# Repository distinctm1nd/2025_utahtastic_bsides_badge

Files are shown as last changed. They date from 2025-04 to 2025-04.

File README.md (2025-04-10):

# 2025 Utahtastic BSides Badge

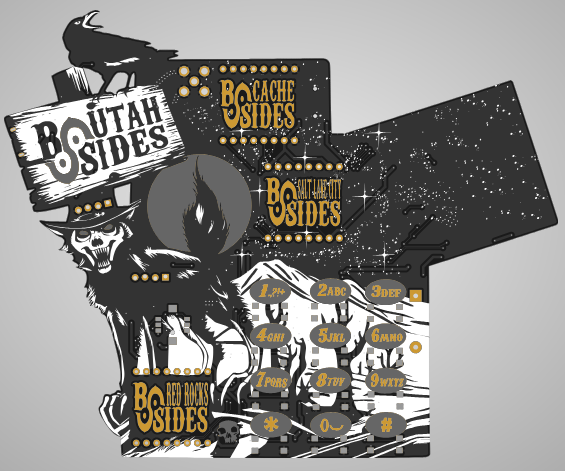
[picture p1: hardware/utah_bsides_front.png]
Utah BSides Badge front


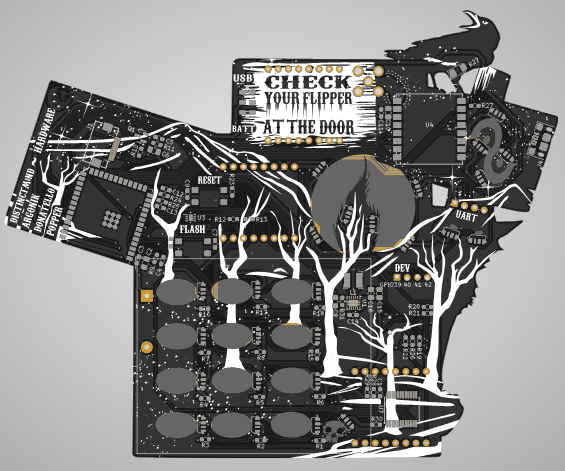
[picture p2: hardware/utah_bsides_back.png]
Utah BSides Badge front


Key Features:

    - ESP32-S3-WROOM Microcontroller
    - LoRa 
    - 25 Addressable LEDs
    - TFT Display
    - Power Options: Powered via Micro USB or 3 AA batteries (regulated at 3.3V).
    - Hackable and Programmable: Easily program with just a laptop and a Micro USB cable.
    - Expansion Ready: 3 minibadge slots for future add-ons.
    - Custom Meshtastic Firmware: Open-source firmware designed for mesh networking.
    - Convenient Controls – UART connection point, Reset and Flash buttons, and a power switch for toggling between USB and battery modes.
    - 4 GPIO pins available for custom dev work

## Make sure you have the following items:

- Badge
- 6 Minibadge headers
- Battery holder
- Moon LED diffuser
- 3 AA Batteries
- Lanyard
- Minibadge kit
- Double sided foam tape

## Badge Assembly

The badge does not require further assembly to be functional by powering through the USB with an external battery. Make sure that the switch is at USB if powering with USB. 

To complete the assembly, first solder the minibadge headers to the badge. Be careful while soldering the header that is near the display. 

After this, solder the battery holder and apply foam tape to hold the end without solder connectors in place. 

Use hot glue to attach the moon diffuser to moon on the back of the badge. 

Attach the lanyard to the "post" by the raven. 

## Minibadge Assembly

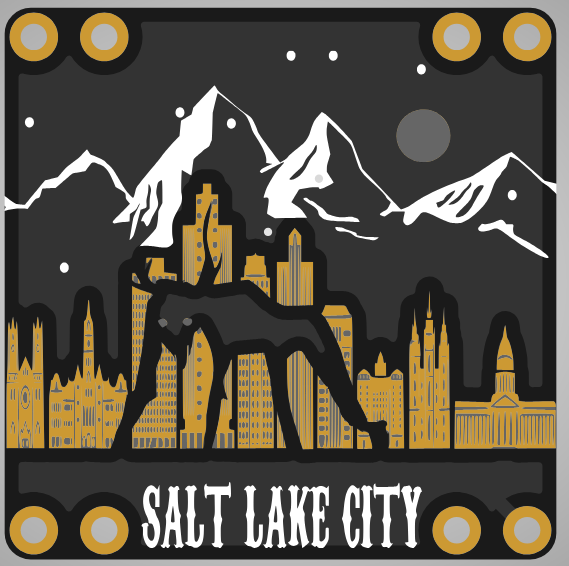
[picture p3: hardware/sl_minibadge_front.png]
Utah BSides Badge front


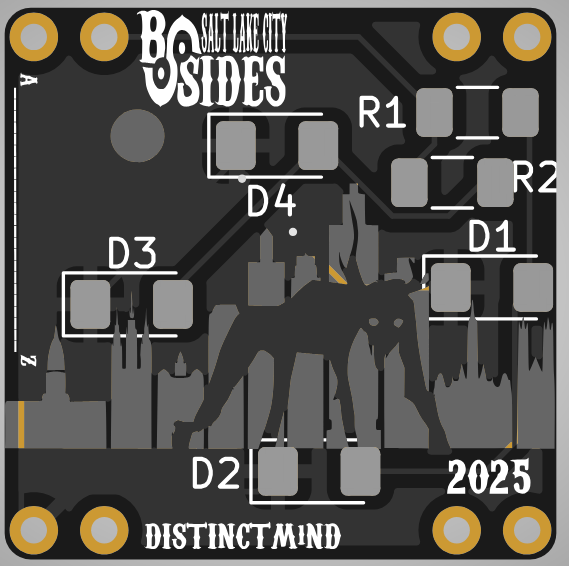
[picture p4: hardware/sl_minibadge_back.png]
Utah BSides Badge front


- Solder the 68 ohm (1206) resistors to R1 and R2. These can be oriented any direction. 
- Solder the LEDs (yellow) to D1, D2, D3 and D4. Orientation on these matters. The green mark is on the cathode side of the LED so it needs to be oriented toward the cathode side on the PCB. The cathode side on the PCB is marked by a box around it. 

- Solder the headers to the four corners. 

## Keyboard Functionality

5-Way Switch
- Up: send message
- Down: erase/backspace
- Left: move cursor left
- Right: move cursor right
- Press: switch screens

## STL Files for joystick button cap and moon diffuser

[Joystick Button Cap](https://www.printables.com/model/1166931-joystick-cap-for-b-sides-utah-2025-badge)

[Moon Diffuser](https://www.printables.com/model/1166783-moon-led-diffuser-for-b-sides-utah-2025-badge)

## A few notes on usage

Don't transmit without the antenna attached as you could damage the badge. 

If you download the meshtastic app you can connect to your badge via bluetooth and send /receive messages through the app. You can also change many setting through the app. 

Make sure that you are on the Medium Fast channel for the conference. 

To change the moon LED color or brightness, in the app, go to:
- Radio Configuration -> Ambient Lighting

Once in the ambient lighting config you can change the brightness of the moon LEDs by changing "Current" to a different number. 255 is max brightness and anything less than that is dimmer. You can change the color codes for Red, Green and Blue to generate different colors. 

If you can't send or receive messages make sure that the LoRa channel is not on long fast. For the conference we'll be using medium fast. 

If the badge doesn't start up when turned on then push the reset button.

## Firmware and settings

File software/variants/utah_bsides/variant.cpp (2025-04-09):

#include "../main.h"
#include "../configuration.h"
#include <Wire.h>
#include "variant.h"
#include <Adafruit_NeoPixel.h>
#include <Preferences.h>
#include "NodeDB.h"

// I2C Expander (TCA9535)
#define TCA9535_ADDRESS 0x20
#define BUTTON_SDA 1
#define BUTTON_SCL 2
#define BUTTON_INT 15

extern graphics::Screen *screen;


// are we showing the welcome screen
int welcomeScreenActivated = 0;

/*-----------------------------------------------------------------------
Definitions and variables for LEDs
-----------------------------------------------------------------------*/
void handleButtonLedFlashing();
void handleChasingLedPatterns();
void handleColorArrayChange();

// Variables for fading button LEDs
unsigned long lastButtonFadeTime = 0;
const unsigned long fadeInterval = 150;  

// Variables for rainbow colors and fading logic
int currentColorIndex = 0;  
float fadeProgress[BUTTON_LED_COUNT] = {0};  
float fadeProgressEye[LOGO_EYE_LED_COUNT] = {0}; 
const float transitionSpeed = 0.01;  

// Variables for chasing eye LEDs
unsigned long lastChaseTime = 0;
const unsigned long chaseInterval = 150; 
int currentLedIndex = 0;  

// Initialize LED objects directly
Adafruit_NeoPixel button_leds(BUTTON_LED_COUNT, BUTTON_LED_PIN, NEO_GRB + NEO_KHZ800);
Adafruit_NeoPixel logo_eye_leds(LOGO_EYE_LED_COUNT, LOGO_EYE_LED_PIN, NEO_GRB + NEO_KHZ800);

const int COLORSCOUNT = 7;

const uint32_t rainbowColors[COLORSCOUNT] = {
    0xFF0000,    // Red
    0xFF00FF,    // Magenta
    0xFFD700,    // Yellow
    0x006400,    // Green
    0x00FF00,    // Blue
    0x800080,    // Indigo
    0xFF1493     // Violet
};

const uint32_t blueWhiteColors[COLORSCOUNT] = {
    0x0000FF,    // Blue
    0xFFFFFF,    // White
    0x0000FF,    // Blue
    0xFFFFFF,    // White
    0x0000FF,    // Blue
    0xFFFFFF,    // White
    0x0000FF     // Blue
};

const uint32_t redMaroonColors[COLORSCOUNT] = {
    0xFF0000,    // Red
    0x800000,    // Maroon
    0xFF0000,    // Red
    0x800000,    // Maroon
    0xFF0000,    // Red
    0x800000,    // Maroon
    0xFF0000     // Red
};

const uint32_t pinkWhiteColors[COLORSCOUNT] = {
    0xFF00FF,    // Pink
    0xFFFFFF,    // White
    0xFF00FF,    // Pink
    0xFFFFFF,    // White
    0xFF00FF,    // Pinkc
    0xFFFFFF,    // White
    0xFF00FF     // Pink
};

const uint32_t pinkPurpleColors[COLORSCOUNT] = {
    0xFF00FF,    // Pink
    0x4B0082,    // Purple
    0xFF00FF,    // Pink
    0x4B0082,    // Purple
    0xFF00FF,    // Pink
    0x4B0082,    // Purple
    0xFF00FF     // Pink
};

const uint32_t greenBlueColors[COLORSCOUNT] = {
    0x00FF00,    // Green
    0x0000FF,    // Blue
    0x00FF00,    // Green
    0x0000FF,    // Blue
    0x00FF00,    // Green
    0x0000FF,    // Blue
    0x00FF00     // Green
};

const uint32_t ledsOff[COLORSCOUNT] = {
    0x000000,    // Black
    0x000000,    // Black
    0x000000,    // Black
    0x000000,    // Black
    0x000000,    // Black
    0x000000,    // Black
    0x000000     // Black
};

const int COLORARRAYCOUNT = 7;
const uint32_t* colorArrays[COLORARRAYCOUNT] = {rainbowColors, blueWhiteColors, redMaroonColors, pinkWhiteColors, pinkPurpleColors, greenBlueColors, ledsOff};

uint32_t activeColorArrayIndex = 0;

/*-----------------------------------------------------------------------
TCA9535 FUNCTIONS --- Keyboard
-----------------------------------------------------------------------*/

#define USE_KEYBOARD_INTERRUPT false

#define KEY(x) meshtastic_ModuleConfig_CannedMessageConfig_InputEventChar_##x

enum ButtonBit {
    BUTTON_BOTLEFT  = 1<<0,
    BUTTON_ZERO     = 1<<1,
    BUTTON_BOTRIGHT = 1<<2,
    BUTTON_NINE     = 1<<3,
    BUTTON_EIGHT    = 1<<4,
    BUTTON_SEVEN    = 1<<5,
    BUTTON_SIX      = 1<<6,
    BUTTON_FIVE     = 1<<7,
    BUTTON_FOUR     = 1<<8,
    BUTTON_THREE    = 1<<9,
    BUTTON_TWO      = 1<<10,
    BUTTON_ONE      = 1<<11,
    BUTTON_UP       = 1<<12,
    BUTTON_RIGHT    = 1<<13,
    BUTTON_DOWN     = 1<<14,
    BUTTON_LEFT     = 1<<15
};

char keys[][6] = {
    {'*',   0,   0,   0,   0,   0},
    {' ', '0',   0,   0,   0,   0},
    {'#',   0,   0,   0,   0,   0},
    {'w', 'x', 'y', 'z', '9',   0},
    {'t', 'u', 'v', '8',   0,   0},
    {'p', 'q', 'r', 's', '7',   0},
    {'m', 'n', 'o', '6',   0,   0},
    {'j', 'k', 'l', '5',   0,   0},
    {'g', 'h', 'i', '4',   0,   0},
    {'d', 'e', 'f', '3',   0,   0},
    {'a', 'b', 'c', '2',   0,   0},
    {'.', ',', '?', '!', '+', '1'},
    {KEY(UP),    0, 0, 0, 0, 0},
    {KEY(RIGHT), 0, 0, 0, 0, 0},
    {KEY(DOWN),  0, 0, 0, 0, 0},
    {KEY(LEFT),  0, 0, 0, 0, 0}
};

#define NUM_ELEMS(a) (sizeof(a)/sizeof a[0])
int konami_code[] = {BUTTON_UP, BUTTON_UP, BUTTON_DOWN, BUTTON_DOWN, BUTTON_LEFT, BUTTON_RIGHT, BUTTON_LEFT, BUTTON_RIGHT, BUTTON_TWO, BUTTON_TWO};
#define KONAMI_CODE_LEN NUM_ELEMS(konami_code)

// forward declaration for use in the keyboard class
void drawMenuScreen(OLEDDisplay *display, OLEDDisplayUiState *state, int16_t x, int16_t y);

void initializeTCA9535() {
    Wire.beginTransmission(TCA9535_ADDRESS);
    Wire.write(0x06); // Set all pins as inputs
    Wire.endTransmission();
}

uint16_t readButtonState() {
    Wire.beginTransmission(TCA9535_ADDRESS);
    Wire.write(0x00); // Request input port 0
    Wire.endTransmission();
    Wire.requestFrom(TCA9535_ADDRESS, 2);
    uint16_t state = Wire.read() | (Wire.read() << 8);
    return ~state;
}

void intPressHandler();
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

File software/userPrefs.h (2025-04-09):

#ifndef _USERPREFS_
#define _USERPREFS_

// Slipstream values:

#define USERPREFS_TZ_STRING "tzplaceholder                                         "

// Uncomment and modify to set device defaults

// #define USERPREFS_EVENT_MODE 1

#define USERPREFS_CONFIG_LORA_REGION meshtastic_Config_LoRaConfig_RegionCode_US
#define USERPREFS_LORACONFIG_MODEM_PRESET meshtastic_Config_LoRaConfig_ModemPreset_MEDIUM_FAST
// #define USERPREFS_LORACONFIG_CHANNEL_NUM 31
// #define USERPREFS_CONFIG_LORA_IGNORE_MQTT true

// #define USERPREFS_CONFIG_GPS_MODE meshtastic_Config_PositionConfig_GpsMode_ENABLED

// #define USERPREFS_CHANNELS_TO_WRITE 3
/*
#define USERPREFS_CHANNEL_0_PSK \
    {                                                                                                                            \
        0x38, 0x4b, 0xbc, 0xc0, 0x1d, 0xc0, 0x22, 0xd1, 0x81, 0xbf, 0x36, 0xb8, 0x61, 0x21, 0xe1, 0xfb, 0x96, 0xb7, 0x2e, 0x55,  \
            0xbf, 0x74, 0x22, 0x7e, 0x9d, 0x6a, 0xfb, 0x48, 0xd6, 0x4c, 0xb1, 0xa1                                               \
    }
*/
// #define USERPREFS_CHANNEL_0_NAME "DEFCONnect"
// #define USERPREFS_CHANNEL_0_PRECISION 14
// #define USERPREFS_CHANNEL_0_UPLINK_ENABLED true
// #define USERPREFS_CHANNEL_0_DOWNLINK_ENABLED true
/*
#define USERPREFS_CHANNEL_1_PSK \
    {                                                                                                                            \
        0x00, 0x00, 0x00, 0x00, 0x00, 0x00, 0x00, 0x00, 0x00, 0x00, 0x00, 0x00, 0x00, 0x00, 0x00, 0x00, 0x00, 0x00, 0x00, 0x00,  \
            0x00, 0x00, 0x00, 0x00, 0x00, 0x00, 0x00, 0x00, 0x00, 0x00, 0x00, 0x00                                               \
    }
*/
// #define USERPREFS_CHANNEL_1_NAME "REPLACEME"
// #define USERPREFS_CHANNEL_1_PRECISION 14
// #define USERPREFS_CHANNEL_1_UPLINK_ENABLED true
// #define USERPREFS_CHANNEL_1_DOWNLINK_ENABLED true
/*
#define USERPREFS_CHANNEL_2_PSK \
    {                                                                                                                            \
        0x00, 0x00, 0x00, 0x00, 0x00, 0x00, 0x00, 0x00, 0x00, 0x00, 0x00, 0x00, 0x00, 0x00, 0x00, 0x00, 0x00, 0x00, 0x00, 0x00,  \
            0x00, 0x00, 0x00, 0x00, 0x00, 0x00, 0x00, 0x00, 0x00, 0x00, 0x00, 0x00                                              \
    }
*/
// #define USERPREFS_CHANNEL_2_NAME "REPLACEME"
// #define USERPREFS_CHANNEL_2_PRECISION 14
// #define USERPREFS_CHANNEL_2_UPLINK_ENABLED true
// #define USERPREFS_CHANNEL_2_DOWNLINK_ENABLED true

// #define USERPREFS_CONFIG_OWNER_LONG_NAME "My Long Name"
// #define USERPREFS_CONFIG_OWNER_SHORT_NAME "MLN"


#define USERPREFS_SPLASH_TITLE "UTAHtastic"
#define icon_width 100
#define icon_height 87
#define USERPREFS_HAS_SPLASH

static unsigned char icon_bits[] = {
 0x00, 0x00, 0x00, 0x40, 0x7f, 0x00, 0x00, 0x00, 0x00, 0x00, 0x00, 0x00, 0x00, 0x00, 0x00, 0x2a, 
	0xe8, 0xa3, 0x00, 0x00, 0x00, 0x00, 0x00, 0x00, 0x00, 0x00, 0x00, 0xc0, 0xff, 0x47, 0x50, 0x01, 
	0x00, 0x00, 0x00, 0x00, 0x00, 0x00, 0x00, 0x00, 0xf8, 0xff, 0x07, 0x7c, 0x00, 0x00, 0x00, 0x00, 
	0x00, 0x00, 0x00, 0x00, 0x00, 0xfc, 0xff, 0x07, 0x1f, 0x00, 0x00, 0x00, 0x00, 0x00, 0x00, 0x00, 
	0x00, 0x00, 0xfe, 0xe8, 0x83, 0x07, 0x00, 0x00, 0x00, 0x00, 0x00, 0x00, 0x00, 0x00, 0x00, 0xff, 
	0xc1, 0xf1, 0x01, 0x00, 0x00, 0x00, 0x00, 0x00, 0x00, 0x00, 0x00, 0x80, 0xff, 0xff, 0xf8, 0x00, 
	0x00, 0x00, 0x00, 0x00, 0x00, 0x00, 0x00, 0x00, 0xc0, 0xff, 0x7f, 0x7c, 0x00, 0x00, 0x00, 0x00, 
	0x00, 0x00, 0x00, 0x00, 0x00, 0xe0, 0xff, 0x3f, 0x3e, 0x00, 0x00, 0x00, 0x00, 0x00, 0x00, 0x00, 
	0x00, 0x00, 0xf0, 0xff, 0x7f, 0x1c, 0x00, 0x00, 0x00, 0x00, 0x00, 0x00, 0x00, 0x00, 0x00, 0xf8, 
	0xff, 0x7f, 0x38, 0x00, 0x00, 0x00, 0x00, 0x00, 0x00, 0x00, 0x00, 0x00, 0xfc, 0xff, 0xff, 0x71, 
	0x00, 0x00, 0x00, 0x00, 0x00, 0x00, 0x00, 0x00, 0x00, 0xfe, 0xff, 0xff, 0x83, 0x03, 0x00, 0x00, 
	0x00, 0x00, 0x00, 0x00, 0x00, 0x00, 0xff, 0xff, 0xff, 0x5f, 0x15, 0x00, 0x00, 0x00, 0x00, 0x00, 
	0x00, 0x00, 0x00, 0xfe, 0xff, 0xff, 0xff, 0x3b, 0x00, 0x00, 0x00, 0x00, 0x00, 0x00, 0x00, 0x00, 
	0xff, 0xff, 0xff, 0xff, 0x77, 0x00, 0x00, 0x00, 0x00, 0x00, 0x00, 0x00, 0x00, 0xff, 0xff, 0xff, 
	0x7f, 0xf2, 0x00, 0x00, 0x00, 0x00, 0x00, 0x00, 0x00, 0x00, 0xff, 0xff, 0xff, 0x7f, 0x01, 0x00, 
	0x00, 0x00, 0x00, 0x00, 0x00, 0x00, 0x00, 0xff, 0xff, 0xff, 0xff, 0x03, 0x00, 0x00, 0x00, 0x00, 
	0x00, 0x00, 0x00, 0x00, 0xff, 0xff, 0xff, 0xff, 0x17, 0x00, 0x00, 0x00, 0x00, 0x00, 0x00, 0x00, 
	0x00, 0xff, 0xff, 0xff, 0xff, 0x3f, 0x00, 0x00, 0x00, 0x00, 0x00, 0x00, 0x00, 0x00, 0xff, 0xff, 
	0xff, 0xff, 0x7f, 0x00, 0x00, 0x00, 0x00, 0x00, 0x00, 0x00, 0x00, 0xfe, 0xff, 0xff, 0xff, 0xff, 
	0x01, 0x00, 0x00, 0x00, 0x00, 0x00, 0x00, 0x00, 0xff, 0xff, 0xff, 0xff, 0xff, 0x07, 0x00, 0x00, 
	0x00, 0x00, 0x00, 0x00, 0x00, 0xfe, 0xff, 0xff, 0xff, 0xff, 0x1f, 0x00, 0x00, 0x00, 0x00, 0x00, 
	0x00, 0x00, 0xfe, 0xff, 0xff, 0xff, 0xff, 0x7f, 0x00, 0x00, 0x00, 0x00, 0x00, 0x00, 0x00, 0xfe, 
	0xff, 0xff, 0xff, 0xff, 0xff, 0x00, 0x00, 0x00, 0x00, 0x00, 0x00, 0x00, 0xfc, 0xff, 0xff, 0xff, 
	0xff, 0xff, 0x07, 0x00, 0x00, 0x00, 0x00, 0x00, 0x00, 0xf8, 0xff, 0xff, 0xff, 0xff, 0xff, 0x0f, 
	0x00, 0x00, 0x00, 0x00, 0x00, 0x00, 0xfc, 0xff, 0xff, 0xff, 0xff, 0xff, 0x1f, 0x00, 0x00, 0x00, 
	0x00, 0x00, 0x00, 0xfe, 0xff, 0xff, 0xff, 0xff, 0xff, 0x3f, 0x00, 0x00, 0x00, 0x00, 0x00, 0x00, 
	0xff, 0xff, 0xff, 0xff, 0xff, 0xff, 0x7f, 0x01, 0x00, 0x00, 0x00, 0x00, 0x00, 0xff, 0xff, 0xff, 
	0xff, 0xff, 0xff, 0xff, 0x03, 0x00, 0x00, 0x00, 0x00, 0x00, 0xff, 0xff, 0xff, 0xff, 0xff, 0xff, 
	0xff, 0x1f, 0x00, 0x00, 0x00, 0x00, 0x00, 0xff, 0xff, 0xff, 0xff, 0xff, 0xff, 0xff, 0x3f, 0x00, 
	0x00, 0x00, 0x00, 0x00, 0xff, 0xff, 0xff, 0xff, 0xff, 0xff, 0xff, 0x7f, 0x00, 0x00, 0x00, 0x00, 
	0x00, 0xff, 0xff, 0xff, 0xff, 0xff, 0xff, 0xff, 0xff, 0x01, 0x00, 0x00, 0x00, 0x00, 0xff, 0xff, 
	0xff, 0xff, 0xff, 0xff, 0xff, 0xff, 0x07, 0x00, 0x00, 0x00, 0x00, 0xfe, 0xff, 0xff, 0xff, 0xff, 
	0xff, 0xff, 0xff, 0x0f, 0x00, 0x00, 0x00, 0x00, 0xff, 0xff, 0xff, 0xff, 0xff, 0xff, 0xff, 0xff, 
	0x7f, 0x00, 0x00, 0x00, 0x00, 0xfe, 0xff, 0xff, 0xff, 0xff, 0xff, 0xff, 0xff, 0xff, 0x01, 0x00, 
	0x00, 0x00, 0xfc, 0xff, 0xff, 0xff, 0xff, 0xff, 0xff, 0xff, 0xff, 0x07, 0x00, 0x00, 0x00, 0xf8, 
	0xff, 0xff, 0xff, 0xff, 0xff, 0xff, 0xff, 0xff, 0x0f, 0x00, 0x00, 0x00, 0xf4, 0xff, 0xff, 0xff, 
	0xff, 0xff, 0xff, 0xff, 0xff, 0x1f, 0x00, 0x00, 0x00, 0x80, 0xff, 0xff, 0xff, 0xff, 0xff, 0xff, 
	0xff, 0xff, 0x3f, 0x00, 0x00, 0x00, 0x04, 0xff, 0xff, 0xff, 0xff, 0xff, 0xff, 0xff, 0xff, 0x15, 
	0x00, 0x00, 0x00, 0x0c, 0xfc, 0xff, 0xff, 0xff, 0xff, 0xff, 0xff, 0xff, 0x07, 0x00, 0x00, 0x00, 
	0x14, 0xf0, 0xff, 0x7f, 0xff, 0xff, 0xff, 0xff, 0xff, 0x1f, 0x00, 0x00, 0x00, 0x28, 0xe0, 0xff, 
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
};
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

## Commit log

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2025-01-31 Add files via upload
    final schematic and pcb files
    [2025_bsides_badge_v2.kicad_sch]
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2025-02-08 key changes: up for sending, down for erasing. Add bottom left and right buttons.
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2025-04-07 Fix keyboard hang by using polling instead of interrupts.
    [variant.cpp]
2025-04-09 Fix multi-press and konami code
    [variant.cpp]
2025-04-09 Open the preferences menu by long pressing * to change LED cycles. Also fixes konami code display.
    [variant.cpp]
2025-04-09 fix critical error caused by userprefs. Fix menu bug. Add menu option to factory reset.
    [userPrefs.h, variant.cpp]
2026-10-31 Add Utah BSides 2025 badge (utah_bsides) on Meshtastic 2.7.26
    Everything badge-specific lives in variants/esp32s3/utah_bsides; no
    Meshtastic source is patched.
    - Pins from the badge KiCad board (ESP32-S3, ST7735S, TCA9535 keypad,
    WS2812 keypad/logo/moon LEDs, LLCC68 or SX1262 LoRa)
    - New keypad driver: per-key debounce, multi-tap that only replaces
    letters that reached the draft, # = Enter, * = Backspace/Back,
    hold * = badge menu, hold # = next LED scene, hold digit = digit
    - 35 LED scenes on their own 50 Hz thread (replaces the 2025 patch to
    AmbientLightingThread.h), settings in NVS, old palette choice kept
    - Badge menu built on the 2.7 banner menus
    - Radio: probes SX1262 then LLCC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
2026-10-31 utah_bsides: badge apps, games, mesh features, pictures
    - Badge app framework (full-screen apps as alert frames, keys routed
    to the open app); tap a digit opens the badge message editor with a
    letter strip, case modes and character count; hold a digit to
    quick-send a canned message
    - Lights app with live preview and LED map; APP COLOUR scenes from
    the phone's Ambient Lighting colour; message/mesh/achievement LED
    alerts; LEDs dim or turn off while the screen sleeps; night mode;
    screen colour themes
    - Name tag (owner name, short name, tagline) and picture gallery;
    tools/make_images.py turns images/ into dithered XBM at build time
    - Games: Simon, Whack-a-mole, Snake, Blocks, Tic-t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
2026-10-31 utah_bsides: joystick angle setup, simpler name tag, LEDs stay on
    - Joystick switches are read together: two switches closing at once
    count as the direction between them, and a correction (eight 45 deg
    angles plus a lean for single-switch pushes) is set on the badge in
    Settings > Joystick setup (push up, push right, check, save)
    - Name tag shows just the name (typed on the badge, defaults to the
    Meshtastic name) with an optional tagline; "HELLO my name is" removed
    - LEDs no longer dim when the screen sleeps unless chosen in Settings
    Claude-Session: https://claude.ai/code/session_01DLgdSHFAqjaN13yft5ZR47
2026-10-31 utah_bsides: fix build: Simon state INPUT clashed with Arduino's INPUT macro
    Prefix the short state names in the badge apps so no Arduino, ESP-IDF
    or Meshtastic macro can collide with them.
    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
2026-11-01 utah_bsides: centre press selects, one navigation rule, zoned LED scenes
    - Joystick centre press (GPIO7) is read by the badge keypad driver:
    click = select everywhere, hold = badge menu; badge apps get it as #.
    BUTTON_PIN is no longer defined so Meshtastic doesn't also act on it.
    - One rule on every screen: up/left = previous, down/right = next,
    centre = select, * = back. Lights is now a plain list; selecting
    Scene opens a live-preview scene list (select keeps, * restores).
    - New scene engine: each scene is a palette plus its own effect for the
    keypad, logo, eyes and moon (12 + 7 + 7 + 7 effects, 32 scenes).
    Key presses flash in the scene's highlight colour. The moon follows
    th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
2026-11-01 utah_bsides: reliable multi-tap, Old West scenes, no LED flicker
    Typing: the keypad thread read the time before polling the I2C expander,
    then ticked the editor with that older time. The tapped letter had been
    stamped a millisecond later, so the unsigned "is it a second old yet"
    check wrapped round and committed the letter at once: 8 8 typed "tt"
    instead of "u" most of the time. Apps are now ticked with a fresh time
    and the editor's timing check is wrap-safe. A host test reproduces it.
    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
2026-11-01 utah_bsides: joystick works the right way round without setup
    The joystick sits about 45 degrees round on every badge: straight up
    closes UP+RIGHT and straight down DOWN+LEFT. With no correction saved,
    DOWN+LEFT read as left, which Meshtastic's menus treat as previous, so
    pushing down moved up. The default is now angle 8 (7 steps), which reads
    all four pushes correctly; Joystick setup is only needed if a badge
    differs. The badge also waits 60 ms (was 35) for the second switch of an
    angled push, so a slightly slow push isn't read as one switch.
    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
2026-11-01 utah_bsides: learn the joystick, right screen colours, name fonts, Old West pictures
    Joystick setup now asks for all four directions and learns which
    switches each push closes, so any mounting works (rotated by any angle
    or mirrored). The learned pushes are saved in NVS ("joymap") and used
    for every menu and game; the setup shows what it learned (e.g.
    "U14 R12 D23 L34") so a wrong badge can be reported.
    Screen colour: the ST7735S panel takes colours blue-first, so red showed
    as blue and amber as light blue. Red and blue are swapped before the
    colour is sent.
    Name tag: font (Classic, Wood type, Serif, Typewriter, Fancy) and size
    (Auto, Big, Medium, Small) in Settings, or 1 / 2 on the name p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
2026-11-01 utah_bsides: Skinwalker Mine (Doom-style), chess, typing lights, skull LED
    Games: Skinwalker Mine, a Doom-style raycaster shooter (six-shooter,
    seven skinwalkers in an old silver mine, health on the keypad, a skull
    heartbeat that speeds up as they close in), and chess against the badge
    (Easy / Normal / Hard) or two players. The chess rules are checked
    against the standard perft counts (tools/chess_test.cpp); the shooter's
    level, shooting and damage are checked in tools/mine_preview.cpp.
    LEDs: the keys light up warm white while a text box is open, so the
    printing is readable, and a pressed key turns green (outside typing, a
    colour that contrasts with the scene). The skull left of * now has i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
2026-11-01 utah_bsides: fix build: chess helper sq() clashed with Arduino's sq() macro
    Arduino.h defines sq(x) as a macro, so the chess board helper
    sq(file, rank) was expanded by the preprocessor and the Chess class fell
    apart. Renamed to sqAt().
    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
2026-11-01 utah_bsides: Mesh settings on the badge, five Skinwalker Mine chapters
    Mesh settings (badge menu): node long/short name, channels (list, show
    the key to share, rename, re-key, remove, and join or create a channel
    with a random, typed, default or no key; new channels are secondary, the
    primary is view-only so the badge can't drop off the shared mesh), which
    channel the editor sends on, transmit power (restarts like the app), hop
    limit, quick-send message editing, and shortcuts to Meshtastic's region/
    preset/role pickers and Bluetooth toggle. Saved the way AdminModule
    saves them. Lights gets a Brand colour row for the Your Brand scenes.
    The 1 key adds + / = for typing base64 keys (tested).
    Sk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
2026-11-01 utah_bsides: fix build: leave out modules for hardware the badge doesn't have
    The firmware was 7.6 KB over the 2,424,832-byte app partition. Leave out
    Meshtastic modules the badge can't use (Paxcounter, ATAK, detection
    sensor, remote hardware, power stress, dropzone, power / health /
    air-quality telemetry) with the standard MESHTASTIC_EXCLUDE_* flags, as
    other official variants do. Every reference to them in Meshtastic is
    behind those flags.
    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
2026-11-01 utah_bsides: pack the pictures, keep every Meshtastic module
    The pictures stored every frame in full (122 KB). Store each frame as
    the XOR with the frame before, PackBits-coded: 21 KB, about 100 KB back,
    every picture and animation unchanged (tools/image_test.cpp checks each
    frame against a checksum of the original pixels). The name tag unpacks
    frames as it plays them.
    That leaves plenty of room, so the modules left out to fit (Paxcounter,
    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
2026-11-05 utah_bsides: v2 release — games, fox hunt, messages, web installer
    Second badge firmware version (Meshtastic 2.7.26 base). Highlights since the
    2025 firmware:
    - Messages reworked as per-chat phone-style threads; private groups, invites,
    QR, re-key; names instead of numbers.
    - Fox hunt + scanning: LoRa/WiFi/BT hunts, following-you + attack detection,
    sub-GHz scanner, node radar, sightings log, flagged devices, packet capture.
    Fox hunt menu grouped: scanners, then logs/watch/lists, then settings.
    - Games: Skinwalker Mine (3D), Chess, CHIP-8 arcade, Solitaire, Mahjong, Simon,
    Whack-a-mole, Snake, Blocks, tic-tac-toe.
    - Tile launcher with arrange/hide; Mesh pages opens as an overlay m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
2026-11-05 Port the UTAHtastic badge to Meshtastic 2.8.2
    Brings the badge (variants/esp32s3/utah_bsides) up on the 2.8.2 base. All
    changes are badge-folder or the known editable root files; src/ is left
    identical to upstream v2.8.2 (the merge introduced duplicate declarations in
    a handful of headers/sources, removed here so src/ matches upstream exactly
    and future merges stay clean).
    Build / framework (platformio.ini):
    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
2026-11-06 badge: turn Bluetooth on from the BT remote page
    When the BT remote app is opened with Bluetooth off, the off-screen now
    offers "Press 5 to turn it on" instead of only telling the user to go to Mesh
    settings. ESP32 releases the BT controller memory at boot when Bluetooth is
    disabled, so it can only come back with a restart; key 5 sets
    config.bluetooth.enabled, reloads config and schedules the reboot, saving the
    trip out to the Mesh settings menu and back.
2026-11-06 badge: port the UTAHtastic badge to Meshtastic 2.8.2
    BLE: move the scanner, BLE explore and tracker-beep onto the Arduino
    framework's own BLE library (NimBLE-backed), which rides on Meshtastic
    2.8's IDF NimBLE host. Drop the h2zero NimBLE-Arduino dependency, the
    nimble_use_idf_host.py host-patch script and its lib_ignore override
    (now inherited from esp32_common unchanged), and the NimBLE-Arduino
    special-case in fix_includes.py. The central/observer roles and the
    raised BLE activity/connection counts stay in custom_sdkconfig - the
    framework BLE host needs them.
    Remove the Bluetooth remote (unreachable HID on 2.8 without src edits):
    delete AppBleRemote.cpp, its menu tile/glyph, and its porta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
2026-11-06 badge: expand README (minibadge ideas, dev pins, UART header)
    Add a "Minibadge ideas" list under Minibadges, and two Hardware-notes
    sections: the GPIO39-42 dev/expansion pins (capabilities and project
    ideas, with the SPI/I2C "both hardware controllers are already used"
    caveat), and the UART header (3V3/GND/TX=GPIO43/RX=GPIO44, console at
    115200, and a warning not to back-feed the 3V3 rail while USB or the
    batteries are connected). Plus the maintainer's own README edits.
2026-11-06 badge: bring hardware, mcp-server and the front-page README onto this branch
    Pull the repo's non-firmware content that only lived on utah-bsides-badge
    onto utah-bsides-2.8.2, additively (no merge, nothing of ours changed):
    - hardware/ (KiCad PCB + schematic + board renders)
    - mcp-server/ (hardware test harness)
    - .gitpod.yml
    - .github/README.md -> symlink to variants/esp32s3/utah_bsides/README.md,
    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
2026-11-06 badge: fix hold-digit shortcut defaults off-by-one (3 opened WiFi, not BT)
    SC_DEFAULTS is indexed directly by the held digit, but it was written as a
    1-based list, so SC_DEFAULTS[3] was "wifi" and a clean install mapped hold-3
    to the WiFi scanner instead of the Bluetooth one (hold-2 was Bluetooth, etc).
    Re-align the array to the digit index: slot 0 = hold-0, slots 1..9 = hold-1..9,
    so hold-3 is "ble" again. Only affects fresh/erased installs (the web
    installer factory-erases); a device with saved shortcuts in NVS was unaffected,
    which is why the locally-updated badge looked correct.
2026-11-06 badge: 3 opens device options in the scanner, stop it relaunching the scan
    The WiFi/Bluetooth scanner uses digit keys for its own controls (3 = the
    selected device's options: nickname/watch/beep/Explore), but numberShortcuts
    was true, so a held digit ran a global shortcut - holding 3 fired the "ble"
    shortcut and relaunched the scan instead of opening options. Turn
    numberShortcuts off for this app, and let 3 act on the highlighted device
    (the first one) even before you move the selection.
2026-11-06 badge: scanner options on joystick-right, wider shortcuts, lock + beep fixes
    - Scanner (WiFi/BT): the device options (Explore/nickname/watch/beep) move from
    the 3 key to a joystick-RIGHT push, and digit shortcuts work in the scanner
    again - so a held digit no longer relaunches/resets the scan. Options act on
    the highlighted device even before you move the selection.
    - Lock/attract: after going idle with no PIN set, the first key returns to the
    page you were on instead of the tile home (matches the PIN behaviour).
    - Make it beep: * exits the beep screen at any time, even mid-request.
    - "Lock" shortcut (hold 9 by default) now opens the gif/attract screen even
    when no PIN is set (with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
2026-11-06 badge: scanning disclaimer + README/comment updates for recent changes
    - Fox hunt and scanning: add a liability disclaimer (lawful use only, no
    warranty, use at your own risk) after the intended-uses line.
    - Update the README for this session's changes: the device-options key in a
    WiFi/Bluetooth scan is now a joystick-right push (was a key); the default
    hold-digit shortcuts are 1 flashlight, 2 sightings log, 3 BT, 4 WiFi,
    5 radar, 6 Messages, 7 Badge WiFi, 8 lights, 9 lock, 0 night; shortcuts now
    also work on the tile home and in Explore (not while a pop-up menu is open).
    - Fix the matching stale comment in AppRadioHunt.
2026-11-06 badge: Flagged devices menu on joystick-right too; generalise the disclaimer
    - Flagged devices now opens a device's menu with a joystick-right push (was
    hold *), matching the WiFi/Bluetooth scanner, so the action is consistent.
    - Scanning disclaimer trimmed to a general "use lawfully, as-is, no liability,
    at your own risk" (dropped the specific interception/tracking/legality lines).
2026-11-09 badge: on-device Meshtastic settings, portal WiFi/MQTT config, pwnagotchi/Flipper detectors
    Mesh settings (phone app now optional for these): group Radio / Mesh behavior /
    Power submenus; add rebroadcast mode, node-info interval, neighbor info, telemetry
    interval, power saving, shutdown-on-battery, RX boosted gain, ignore-MQTT.
    Badge WiFi portal: new "Meshtastic network" card (WiFi SSID/PSK/NTP + MQTT) backed
    by /api/meshconfig, persisted via nodeDB->saveToDisk.
    Scanner: detect pwnagotchi beacons (source de:ad:be:ef:de:ad) and Flipper Zero BLE
    adverts (company 0x0FBA); surface pwnagotchi/Flipper counts and the karma
    (SF_MANYNAMES) count in Scan Stats.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
2026-11-09 badge: opt-in research build with active WiFi/BT tools (compiled out of default)
    New utah_bsides_research PlatformIO env defines BADGE_OFFENSIVE. Every tool is behind
    #if BADGE_OFFENSIVE and is absent from the signed default build; gated at runtime by a
    "RESEARCH BUILD" boot page, an on-screen disclaimer (authorized use only), and a
    2-second hold-to-fire.
    Tools (research build only): targeted deauth, beacon spam (karma-style), BLE pairing
    spam (Apple/Google/Windows/Samsung/All), probe-request sniffer, handshake capture to
    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
2026-11-10 badge: defensive threat-detection suite + research probe/lure tools
    Detection (all builds):
    - Threats page aggregating live WiFi+BLE threats; shared /badge/events.csv
    log (threatRecord, one canonical type list, wall-clock epoch when known);
    LED flourish on a new high-severity threat
    - Deauth attacker + target ID; "aimed at YOU" via the trusted-device list
    - Karma/MANA: worst-AP identity, name-count severity, junk-vs-real name lean
    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
2026-11-10 badge: touch README to refresh the GitHub landing-page render (symlinked via .github/README.md)
2026-11-11 badge: never sign or publish the research build
    The research env was being signed by the post-build hook whenever the signing
    key was present, producing .update.bin images any badge would accept over WiFi.
    - sign_update.py skips envs named *research* or built with BADGE_OFFENSIVE
    - sign_file.py refuses anything but firmware-utah_bsides-* images
    - CI refuses to build a research env, signs/releases/deploys only on a
    badge-v* tag push (not a manual run), and fails if a built image contains
    the research boot banner
    - gate the portal's wardrive/probes log routes behind BADGE_OFFENSIVE
    - platformio.ini: correct the list of files holding the gates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
2026-11-11 badge: strict filesystem build in CI; Throttle helpers in the research app
    - CI no longer ignores a failed buildfs or a missing littlefs image
    - AppResearch.cpp: replace bare millis() comparisons with Throttle helpers
2026-11-11 badge: harden the Badge WiFi portal; 12-character password and join QR
    - portal answers only requests addressed to the badge's own address and
    (when an Origin is sent) from its own page, blocking cross-site requests
    and DNS rebinding from other pages on the connected device
    - /api/meshconfig no longer returns the WiFi / MQTT passwords, only whether
    one is saved; blank keeps the saved one, a checkbox removes it
    - the portal WiFi password is 12 random characters in three hyphenated
    groups (was 8)
    - Badge WiFi screen: # shows a WiFi-join QR code for phones
2026-11-11 badge: portal lock session, chunked log downloads, no WiFi downgrades
    - a device that joins the Badge WiFi portal while the badge is PIN-locked is
    refused until it is unlocked; a session already open survives the lock
    - log / capture downloads take the storage lock per 1 KB read instead of for
    the whole transfer
    - unpackFrame() bounds its reads for uploaded pictures
    - free the picture upload buffer when an upload is aborted
    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
